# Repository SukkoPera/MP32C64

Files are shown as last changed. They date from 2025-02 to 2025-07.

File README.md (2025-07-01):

# MP32C64
MP32C64 is a simple adapter that allows connecting any audio source to the Datassette port of a Commodore VIC-20, 64, 128 or Plus/4 computer.

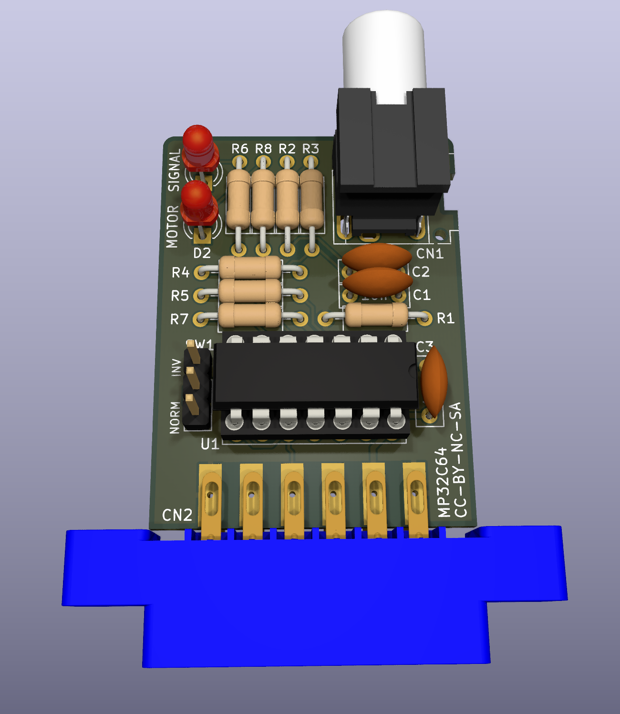
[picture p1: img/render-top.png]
Board


## Summary
With this adapter, any audio source can be used in place of the proprietary Commodore Datassette, in order to load software into a Commodore computer through the dedicated port.

It was originally developed by the Spanish C64 freak Kopsec, probably inspired by the adapter that came with [1st CD-Edition](https://www.c64-wiki.com/wiki/1st_CD-Edition_(Collection)).

As the name suggests, beside Audio CDs, MP3 files will also work, so a smartphone (provided that you have an old model with an audio jack...) or any other audio player can be used.

Another similar project, which works just as well as this one, is [DatassetteAudioAdapter](https://github.com/SukkoPera/DatassetteAudioAdapter).

PRG files can be converted to audio using the [WAV-PRG](https://wav-prg.sourceforge.io/) software suite.

> [!IMPORTANT]
> This adapter only works for playing back audio files, there is no support for recording.

## Assembly
The original adapter used 6.8k and 68k resistors, but I didn't have those values when I built the first prototype, so I used 4.7k and 47k and they worked well. Probably 10k and 100k would also work, so give these a try before buying new resistors for the purpose.

The adapter can either be built with a PJRAN1X1U01X RCA/Cinch connector or with a SJ1-3525N 3.5" headphone jack connector, according to your preference. Note that the RCA connector will point towards the back, while the headphone jack will point to the right.

## Usage
The first thing to do is to set the playback volume: start with 0 and gradually increase it until the *Signal* LED is constantly on. You can still go up a few ticks from there, experiment a bit until you have successful loads.

Second thing is motor control: you have probably noticed that the computer is able to start and stop the Datassette motor at will, but of course it cannot stop an MP3 or CD player, therefore playback control will be on you: keep an eye on the *Motor* LED and pause the playback as soon as possible whenever it goes off, then restart it when it lights up again (for the latter you don't need to rush). This is particularly important when the "FOUND XXX" screen shows up in BASIC, as if you leave the player running, it might run past the data start while the computer is still waiting to start the loading. You can also press the space bar at this point, as it will abort the wait and start the loading immediately.

Also be aware of the *NORM/INV* jumper: this should stay in the *NORM* position for the vast majority of files. In case you know you have one that was encoded with inverse polarity, or if something just doesn't load, you can try the *INV* setting.

One last thing to keep in mind is that the adapter always behaves as if the *Play* button was pressed. Therefore, if a game explicitly asks to stop the Datassette, you will have to unplug the adapter, which is not very nice, so I don't take any responsibility for anything that might happen.

## Releases
If you want to get this board produced, you are recommended to get [the latest release](https://github.com/SukkoPera/MP32C64/releases) rather than the current git version, as the latter might be under development and is not guaranteed to be working.

Every release is accompanied by its Bill Of Materials (BOM) file and any relevant notes about it, which you are recommended to read carefully.

## License
The MP32C64 documentation, including the design itself, is copyright &copy; SukkoPera 2025 and is licensed under the [Creative Commons Attribution-NonCommercial-ShareAlike 4.0 International License](https://creativecommons.org/licenses/by-nc-sa/4.0/).

This documentation is distributed *as is* and WITHOUT ANY EXPRESS OR IMPLIED WARRANTIES whatsoever with respect to its functionality, operability or use, including, without limitation, any implied warranties OF MERCHANTABILITY, SATISFACTORY QUALITY, FITNESS FOR A PARTICULAR PURPOSE or infringement. We expressly disclaim any liability whatsoever for any direct, indirect, consequential, incidental or special damages, including, without limitation, lost revenues, lost profits, losses resulting from business interruption or loss of data, regardless of the form of action or legal theory under which the liability may be asserted, even if advised of the possibility or likelihood of such damages.

## Support the Project
If you want to get some boards manufactured, you can get them from PCBWay through this link:

PCB from PCBWay (https://www.pcbway.com/project/shareproject/MP32C64_Replace_the_Commodore_Datassette_with_any_audio_source_7410640e.html)

You get my gratitude and cheap, professionally-made and good quality PCBs, I get some credit that will help with this and [other projects](https://www.pcbway.com/project/member/shareproject/?bmbid=41100). You won't even have to worry about the various PCB options, it's all pre-configured for you!

Also, if you still have to register, [you can use this link](https://www.pcbway.com/setinvite.aspx?inviteid=41100) to get some bonus initial credit (and yield me some more).

You can also buy me a coffee if you want:

<a href='https://ko-fi.com/L3L0U18L' target='_blank'>Buy Me a Coffee at ko-fi.com</a>

## Thanks
* Kopsec for designing the original adapter.
* [C64-Wiki](https://www.c64-wiki.com/wiki/Main_Page) for preserving the schematics and various information about the adapter.
* Kinmami for validating the design.

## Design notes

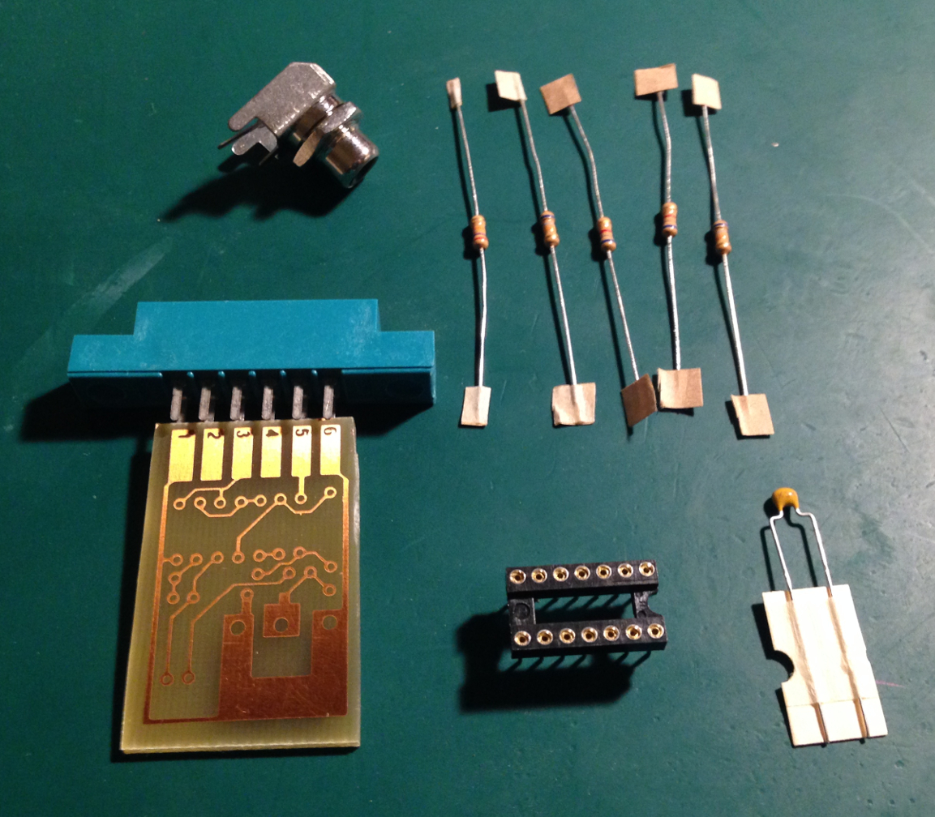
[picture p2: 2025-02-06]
doc/1stCDParts.jpg

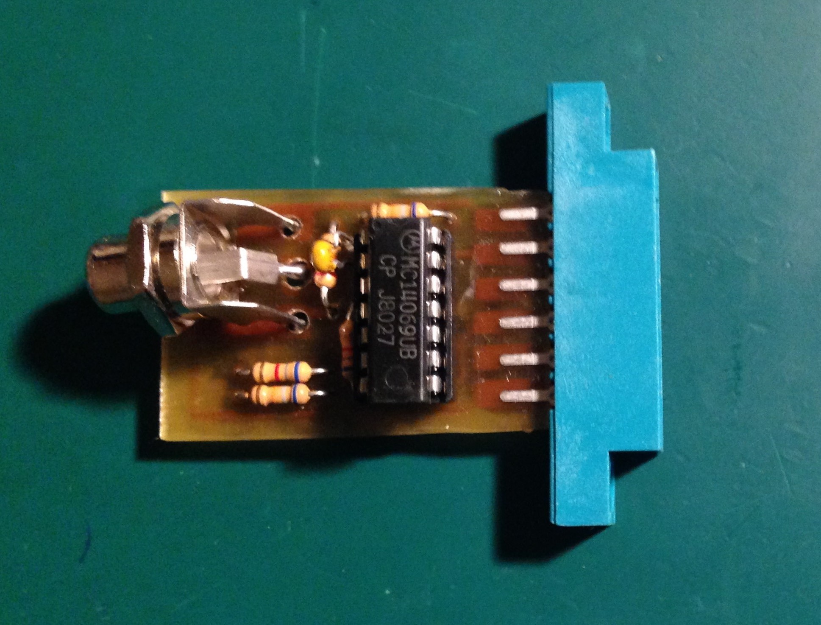
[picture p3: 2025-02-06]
doc/1stCDAdapter2.jpg

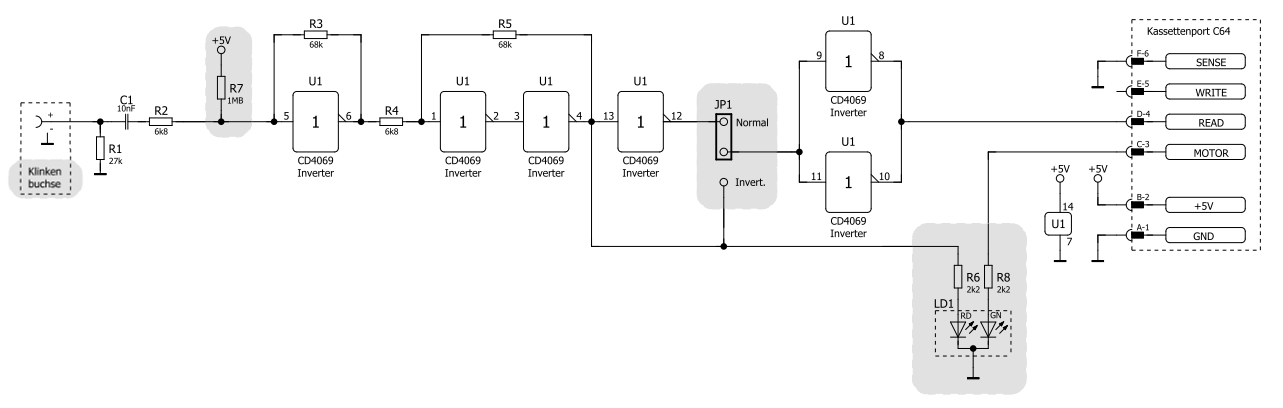
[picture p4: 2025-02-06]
doc/MP32C64-Schaltplan.png

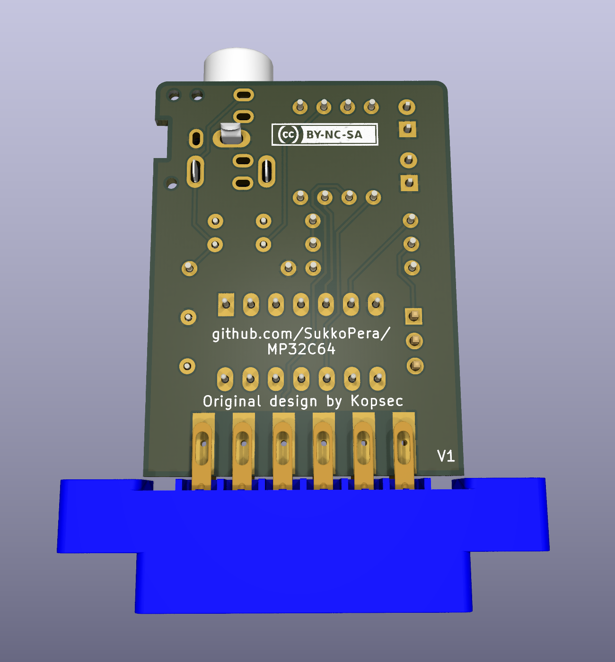
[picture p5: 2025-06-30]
img/render-bottom.png

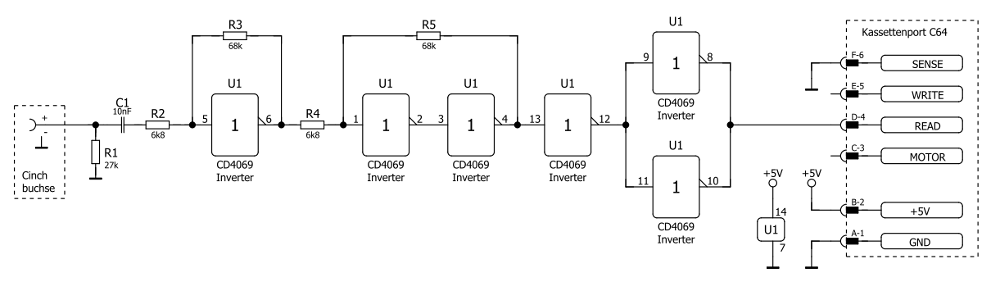
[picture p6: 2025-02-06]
doc/1st_CD-Edition_-_Schaltplan.png

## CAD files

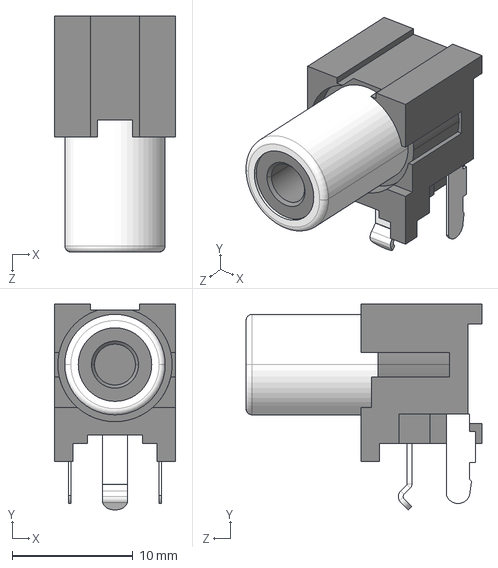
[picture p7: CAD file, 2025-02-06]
3dModels/PJRAN1X1U01X--3DModel-STEP-56544.stp
10.0 x 17.0 x 19.5 mm

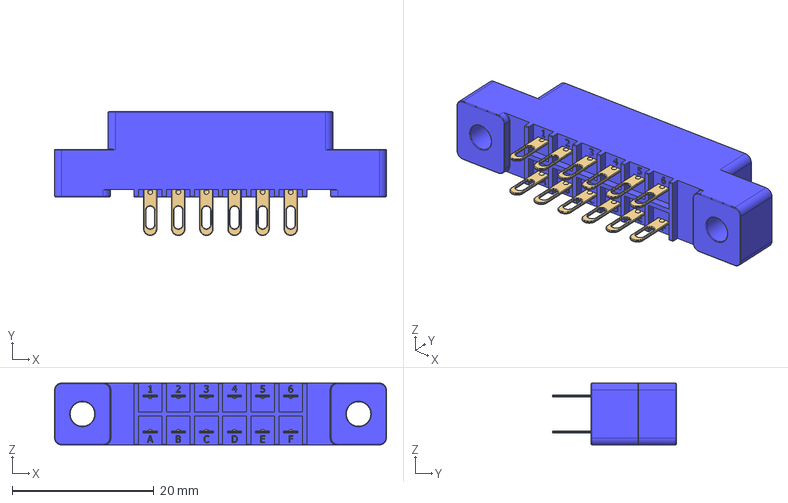
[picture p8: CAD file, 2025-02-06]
3dModels/C64_TapePort.step
46.8 x 17.5 x 8.71 mm
Metallzunge x 12
Card Edge Connector 2x12 (Userport)
Trenner Edge Conn

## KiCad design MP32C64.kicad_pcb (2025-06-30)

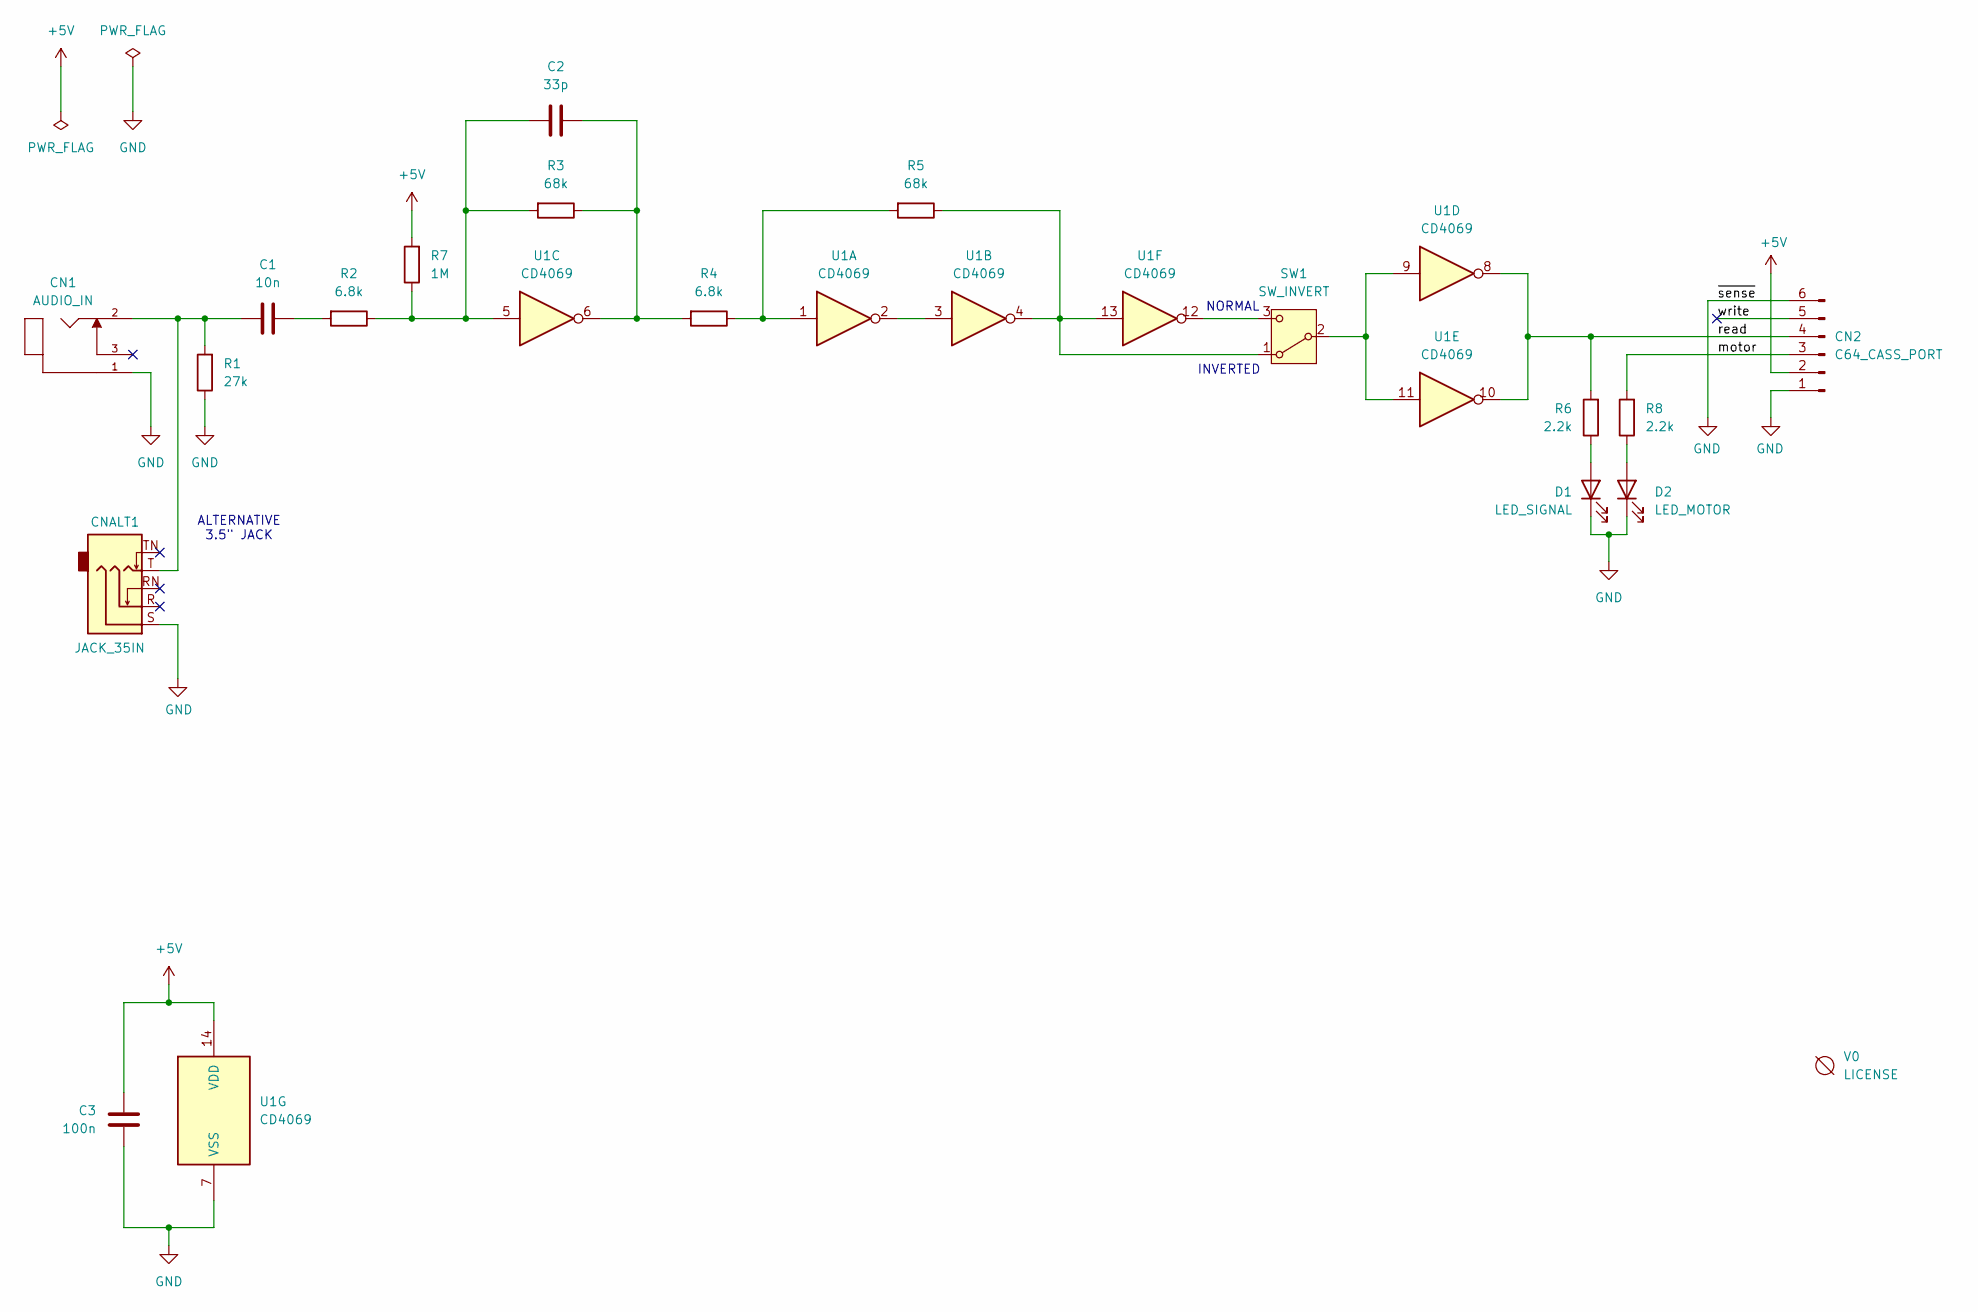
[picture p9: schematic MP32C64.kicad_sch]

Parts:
C1: 10n; C_Disc_D7.0mm_W2.5mm_P5.00mm
C2: 33p; C_Disc_D7.0mm_W2.5mm_P5.00mm
C3: 100n; C_Disc_D7.0mm_W2.5mm_P5.00mm
CN1: AUDIO_IN; SWITCHCRAFT_PJRAN1X1U01X
CN2: C64_CASS_PORT; C64-Cassette-Port-Female
CNALT1: JACK_35IN; AudioJack_SJ1-3525N
D1: LED_SIGNAL; LED_D3.0mm
D2: LED_MOTOR; LED_D3.0mm
R1: 27k; R_Axial_DIN0207_L6.3mm_D2.5mm_P10.16mm_Horizontal
R2, R4: 6.8k; R_Axial_DIN0207_L6.3mm_D2.5mm_P10.16mm_Horizontal
R3, R5: 68k; R_Axial_DIN0207_L6.3mm_D2.5mm_P10.16mm_Horizontal
R6, R8: 2.2k; R_Axial_DIN0207_L6.3mm_D2.5mm_P10.16mm_Horizontal
R7: 1M; R_Axial_DIN0207_L6.3mm_D2.5mm_P10.16mm_Horizontal
SW1: SW_INVERT; PinHeader_1x03_P2.54mm_Vertical
U1: CD4069; DIP-14_W7.62mm_Socket_LongPads
V0: LICENSE; cc_by_nc_sa_small

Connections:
+5V: C3.2, CN2.2, R7.2, U1.14 (VDD)
/motor: CN2.3, R8.2
/read: CN2.4, R6.2, U1.8, U1.10
/write: CN2.5
/write_1: CN2.5
GND: C3.1, CN1.1, CN2.1, CN2.6, CNALT1.S, D1.1 (K), D2.1 (K), R1.1, U1.7 (VSS)
unnamed: C1.1, CN1.2, CNALT1.T, R1.2
unnamed: C1.2, R2.2
unnamed: C2.1, R2.1, R3.2, R7.1, U1.5
unnamed: C2.2, R3.1, R4.2, U1.6
unnamed: D1.2 (A), R6.1
unnamed: D2.2 (A), R8.1
unnamed: R4.1, R5.2, U1.1
unnamed: R5.1, SW1.1 (A), U1.4, U1.13
unnamed: SW1.2 (B), U1.9, U1.11
unnamed: SW1.3 (C), U1.12
unnamed: U1.2, U1.3

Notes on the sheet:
NORMAL
INVERTED
ALTERNATIVE 3.5" JACK

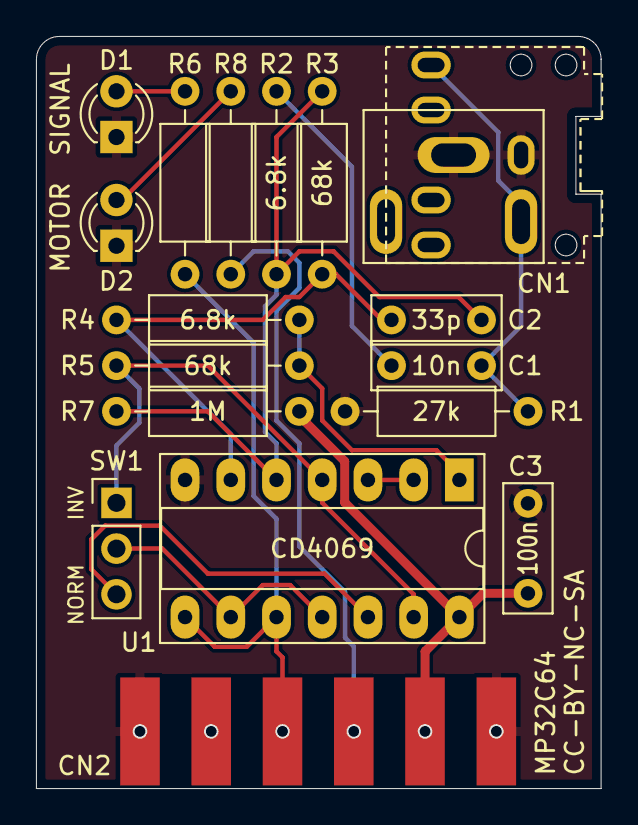
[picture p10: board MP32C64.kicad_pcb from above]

Board: 2 copper layers, 31.4 x 41.8 mm, 19 parts (1 on the bottom side), 15 nets.

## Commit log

2025-02-06 Almost ready
    [MP32C64.kicad_pcb, MP32C64.kicad_sch, PJRAN1X1U01X--3DModel-STEP-56544.stp]
2025-02-10 Add dual support for RCA/3.5" jack connector
    [MP32C64.kicad_pcb, MP32C64.kicad_sch]
2025-03-17 Add license, etc.
    [MP32C64.kicad_pcb, MP32C64.kicad_sch]
2025-03-17 Replace dual LED with 2 separate LEDs
    [MP32C64.kicad_pcb, MP32C64.kicad_sch]
2025-03-25 Add C2, found in some other schematics
    [MP32C64.kicad_pcb, MP32C64.kicad_sch]
2025-04-02 Tidy up
    [MP32C64.kicad_pcb, MP32C64.kicad_sch]
2025-06-30 Fix resistor values & add renders
    [MP32C64.kicad_pcb, MP32C64.kicad_sch]
